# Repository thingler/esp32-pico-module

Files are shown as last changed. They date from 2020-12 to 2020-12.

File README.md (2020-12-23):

# Thingler ESP32-PICO Module

Thingler ESP32-PICO Module is a small size ESP32 development board with a minimum of required external components (including antenna). It's in the size of 20.60 mm x 15.60 mm with 16 pins and can be placed on a breadboard for prototyping. The module can be powered and programmed with the [Thingler ESP32 Programmer](https://github.com/thingler/esp32-programmer) but can also be powered with a separate power supply for small-sized designs.

Thingler ESP32 Programmer schematics and PCB has been designed with KiCad.

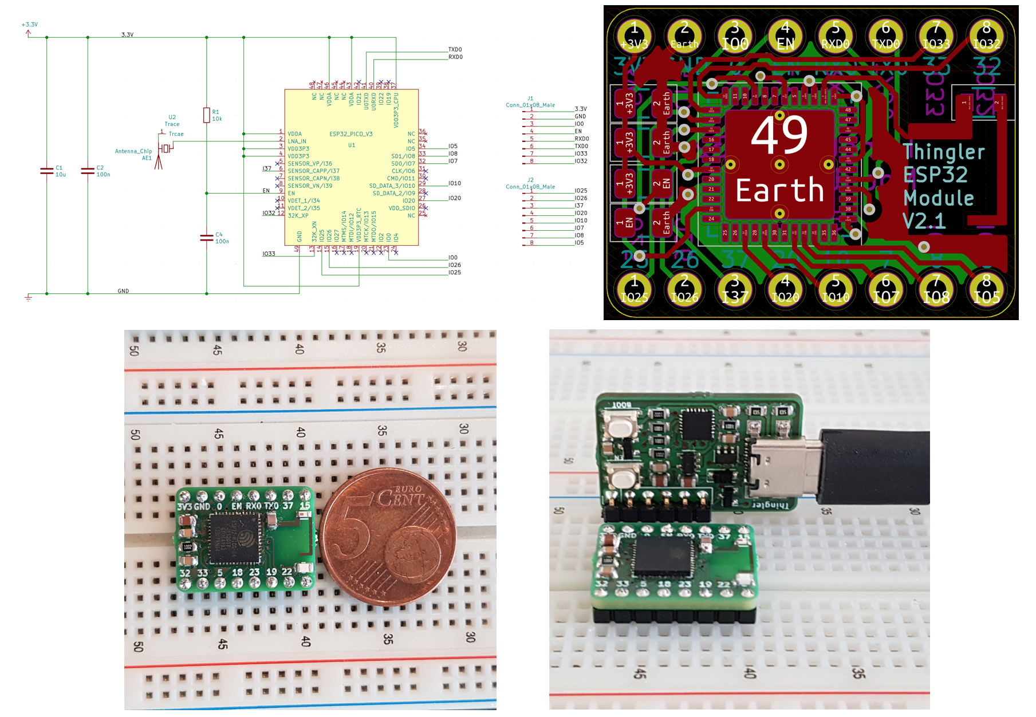
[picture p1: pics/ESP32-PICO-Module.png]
Thingler ESP32-PICO Module


## Getting started

### Requirements

* [KiCad](https://kicad-pcb.org/download/) for the schematics

* [Thingler ESP32 Programmer](https://github.com/thingler/esp32-programmer)

### Pin configuration

Due to the size of the module, only part of the pins from the ESP32 microcontroller is exposed. Many of the ESP32 features can be configured to any of the I/O pins but some considerations has been made during the design of the module. Sice the ADC2 is shared with the WIFI module, which has higher priority, reading operation of adc2_get_raw() will fail between esp_wifi_start() and esp_wifi_stop(). Hence, three ADC1 channels have been exposed from the module in order to read ADC conversions during WIFI operation. Pins for I2S and DAC has also been exposed from the module.

Thingler ESP32-PICO Module has the following pin configuration:

| Name | Microcontroller pin(s) | Type | Function |
| --- | --- | --- | --- |
| 3V3 | 1, 3, 4, 19, 37, 43, 46 | P | Analog power supply (2.3V ~ 3.6V) |
| GND | 49 | P | Analog power supply (ground) |
| IO0 | 23 | I/O | ADC2_CH1, TOUCH1, RTC_GPIO11, CLK_OUT1, EMAC_TX_CLK |
| EN | 9 | I | High: On; enables the module, Low: Off; resets the module |
| RXD0 | 40 | I/O | GPIO3, U0RXD, CLK_OUT2 |
| TXD0 | 41 | I/O | GPIO1, U0TXD, CLK_OUT3, EMAC_RXD2 |
| IO33 | 13 | I/O | 32K_XN (32.768 kHz crystal oscillator output), ADC1_CH5, TOUCH8, RTC_GPIO8 |
| IO32 | 12 | I/O | 32K_XP (32.768 kHz crystal oscillator input), ADC1_CH4, TOUCH9, RTC_GPIO9 |
| IO25 | 14 | I/O | GPIO25, DAC_1, ADC2_CH8, RTC_GPIO6, EMAC_RXD0 |
| IO26 | 15 | I/O | GPIO26, DAC_2, ADC2_CH9, RTC_GPIO7, EMAC_RXD1 |
| IO37 | 6 | I | GPIO37, ADC1_CH1, RTC_GPIO1 |
| IO20 | 27 | I/O | GPIO20 |
| IO10 | 29 | I/O | GPIO10, SD_DATA3, HS1_DATA3, U1TXD |
| IO7 | 32 | I/O | GPIO7, SD_DATA0, HS1_DATA0, U2RTS |
| IO8 | 33 | I/O | GPIO8, SD_DATA1, HS1_DATA1, U2CTS |
| IO5 | 34 | I/O | GPIO5, VSPICS0, HS1_DATA6, EMAC_RX_CLK |

### Build

The PCB wihout components can be ordered from [Aisler](https://aisler.net/p/ZVKSJLOA) or the PCB can be ordered from any fabrication houses by providing the [gerber files](Gerbers).

The following components has been used for the module:

| Ref | Qty | Manufacturer Part Number | Manufacturer | Description | Product Link |
| --- | --- | --- | --- | --- | --- |
| U1 | 1 | ESP32-PICO-V3 | Espressif Systems | RF System on a Chip - SoC SIP module ESP32 with 4MByte Flash, Dual Core MCU, Wi-Fi & Bluetooth Combo, LGA48-pin, 7*7mm | [Mouser](https://www.mouser.fi/ProductDetail/Espressif-Systems/ESP32-PICO-V3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) |
| J1, J2 | 2 | 10129378-908002BLF | Amphenol FCI | Headers & Wire Housings ECONOSTIK HEADER SR VT TH 1X8 | [Mouser](https://www.mouser.fi/ProductDetail/Amphenol-FCI/10129378-908002BLF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) |
| AE1 | 1 | 2450AT14A0100T | Johanson Technology | Antennas SMALL AREA 2.4G ANT | [Mouser](https://www.mouser.fi/ProductDetail/Johanson-Technology/2450AT14A0100T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) |
| C1 | 1 | CGA4J1X7R0J106K125AC | TDK | 10 uF 10% 0805 6.3V | [Mouser](https://www.mouser.fi/ProductDetail/TDK/CGA4J1X7R0J106K125AC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) |
| C2, C4 | 2 | 885012207098 | Wurth Elektronik | 100 nF 10% 0805 50V | [Mouser](https://www.mouser.fi/ProductDetail/Wurth-Elektronik/885012207098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) |
| R1 | 1 | CRCW080510K0FKEAC | Vishay / Dale | Thick Film Resistors - SMD 1/8Watt 10Kohms 1% Commercial Use | [Mouser](https://www.mouser.fi/ProductDetail/Vishay-Dale/CRCW080510K0FKEAC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) |

## License

Released under [GNU/GPL Version 3](LICENSE)

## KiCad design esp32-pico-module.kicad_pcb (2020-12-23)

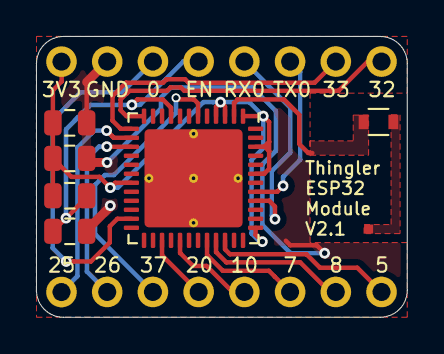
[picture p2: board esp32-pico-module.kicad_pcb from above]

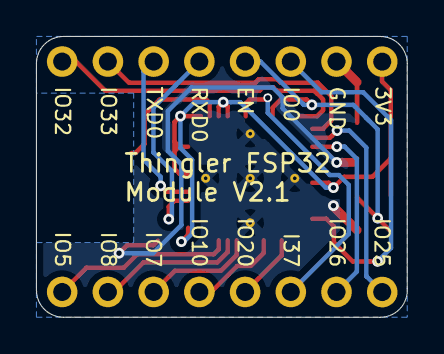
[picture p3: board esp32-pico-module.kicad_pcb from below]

Board: 2 copper layers, 20.6 x 15.6 mm, 9 parts (2 on the bottom side), 18 nets.

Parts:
AE1: Antenna_Chip; wifi antenna
C1: 10u; C_0805_2012Metric
C2, C4: 100n; C_0805_2012Metric
J1, J2: Conn_01x08_Male; PinHeader_1x08
R1: 10k; R_0805_2012Metric
U1: ESP32_PICO_V3; QFN-48
U2: Trace; AntennaTrace

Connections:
+3V3: C1.1, C2.1, J1.1, R1.1, U1.1, U1.3, U1.4, U1.19, U1.37, U1.43, U1.46
/EN: C4.1, J1.4, R1.2, U1.9
/I37: J2.3, U1.6
/IO0: J1.3, U1.23
/IO5: J2.8, U1.34
/IO7: J2.6, U1.32
/IO8: J2.7, U1.33
/IO10: J2.5, U1.29
/IO20: J2.4, U1.27
/IO25: J2.1, U1.14
/IO26: J2.2, U1.15
/IO32: J1.8, U1.12
/IO33: J1.7, U1.13
/RXD0: J1.5, U1.40
/TXD0: J1.6, U1.41
Earth: C1.2, C2.2, C4.2, J1.2, U1.49
unnamed: AE1.1, U1.2
unnamed: AE1.2, U2.1

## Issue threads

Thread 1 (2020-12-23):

Question about PCB

ATMEGA17, 2020-12-23:
Hello, Firs of all thankyou for your efforts i will try to make this module and fabricate it to do that in order to maintain the best performance for the antenna  i noticed you did not make a ground plane
1 - do i have to make a ground plane ?
2 - what is the pcb thickness from wihch you calculated the wire width attached to the antenna via the capacitor to achieve 50ohm of impedance
3 - can you please tell me if the results of your antenna is good ?
4 - can i replace your antenna with chip antenna ?

Thank you very much

jarl-tornroos, 2020-12-23:
Hi, thanks for showing interest in my project!

The ground plane is not there because it’s only a two-layer board and quite crowded with traces. The PCB is ~1.6mm and the copper thickness is ~35µm. The bord is actually already using a chip antenna, 2450AT14A0100T. The antenna circuit design is taken from the datasheet, https://www.mouser.com/datasheet/2/611/2450AT14A0100-1519323.pdf

When I designed the PCB I tried to use a matching circuit from the datasheet but I realized that the signal is much better when connecting a 0 Ohm resistor for C3 and to leave L1 unconnected. I just today removed C3 and L1 from the design and pushed the changes.

The result of the antenna is okayish, not as good as for example the ESP32-PICO-KIT with the Pro Ant 440 antenna but maybe close to my Samsung S8. I’m no expert on antennas so I believe the circuit can be improved.

jarl-tornroos, 2020-12-23:
Also, note that the ESP32-PICO-V3 has a build-in 50 Ohm output impedance circuit from the feed line.

ATMEGA17, 2020-12-24:
Thank you so much for your answers and thank you for sharing the antenna link it was the missing part now after reading it every thing is clear
for commercial and professional uses  I will use the esp32-wroom-32 for the project I am working on now  with its own PCB antenna after that I will certainly build your project test its performance  and keep you on updates

Closed 2023-09-12.

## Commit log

2020-03-30 initial commit :tada:
    [esp32-pico-d4-module-B_Cu.gbr, esp32-pico-d4-module-B_Mask.gbr, esp32-pico-d4-module-B_Paste.gbr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]
2020-04-02 Documentations, license and improved silk screen
    [esp32-pico-d4-module-B_Cu.gbr, esp32-pico-d4-module-B_Mask.gbr, esp32-pico-d4-module-B_Paste.gbr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]
2020-04-02 power supply typo
2020-07-29 updated micrcontroller to use esp32-pico-v3
    [esp32-pico-d4-module.kicad_pcb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]
2020-12-23 Removed extra impedance components for the antenna
    [esp32-pico-module-B_Cu.gbr, esp32-pico-module-B_Mask.gbr, esp32-pico-module-B_Paste.gbr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]
